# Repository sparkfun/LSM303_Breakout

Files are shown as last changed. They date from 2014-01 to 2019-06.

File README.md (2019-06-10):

**NOTE:** *This product has been retired from our catalog. If you are looking for more up-to-date info, please check out some of these resources to see how other users are still hacking and improving on this product.*
* *[SparkFun Forum](https://forum.sparkfun.com/)*
* *[IRC Channel](https://www.sparkfun.com/news/263)*

LSM303DLMTR Breakout Board
===========================

[LSM303 Breakout
*LSM303DLMTR Breakout Board (SEN-10888)*](https://www.sparkfun.com/products/10888)

The LSM303DLMTR is a triple axis accelerometer and triple axis magnetic sensor, providing 6D of orientation detection.

There is example code available [here](https://github.com/pololu/lsm303-arduino).

Repository Contents
-------------------
* **/Hardware** - All Eagle design files (.brd, .sch)

License Information
-------------------
The hardware is released under [Creative Commons Share-alike 3.0](http://creativecommons.org/licenses/by-sa/3.0/).

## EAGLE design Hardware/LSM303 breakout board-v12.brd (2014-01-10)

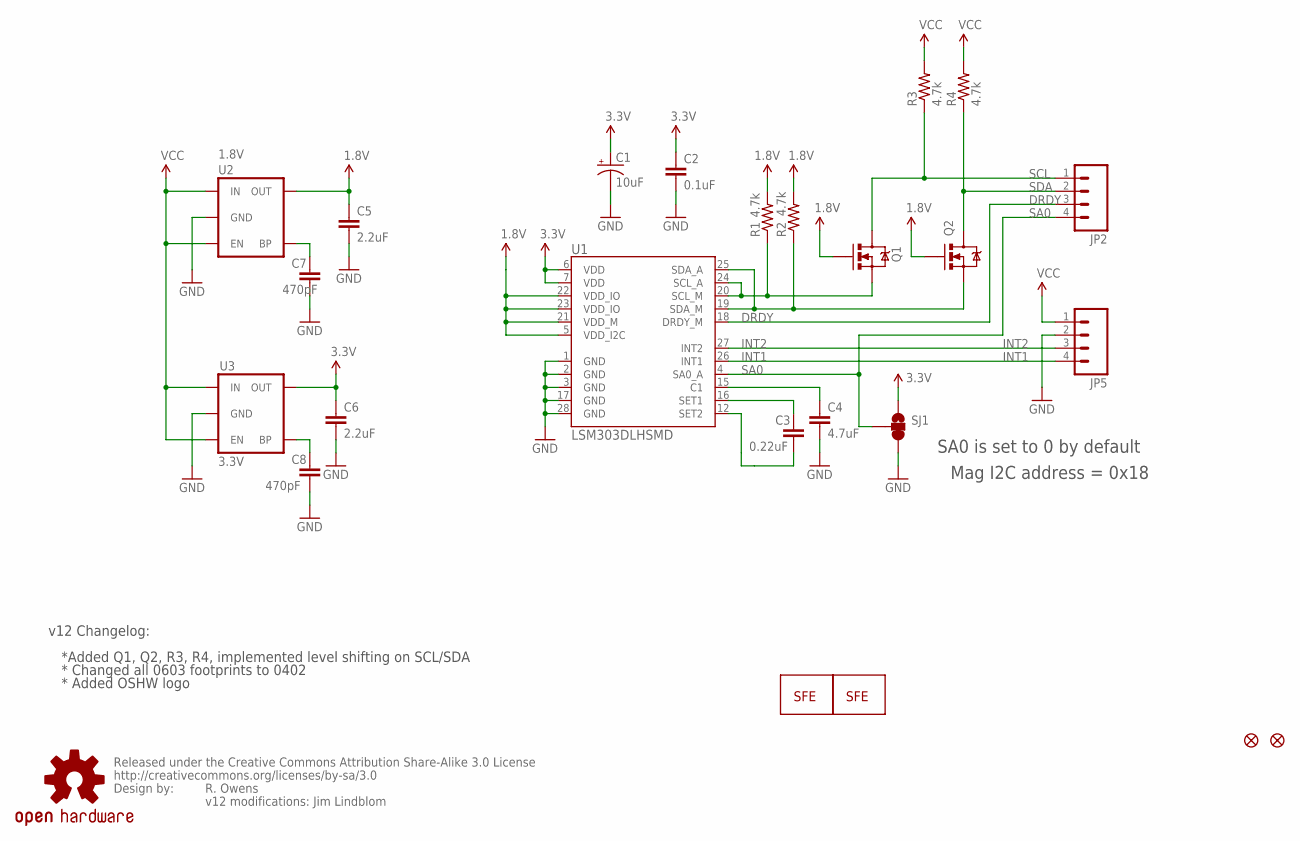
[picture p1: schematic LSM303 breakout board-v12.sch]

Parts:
C1: 10uF; EIA3216
C2: 0.1uF; 0402-CAP
C3: 0.22uF; 0402-CAP
C4: 4.7uF; 0402-CAP
C5, C6: 2.2uF; 0402-CAP
C7, C8: 470pF; 0402-CAP
JP1: LOGO-SFENW2; SFE-NEW-WEB
JP2, JP5: M04PTH; 1X04
JP3, JP4: FIDUCIAL1X2; FIDUCIAL-1X2
JP6: LOGO-SFESK; SFE-LOGO-FLAME
Q1, Q2: MOSFET-N-CH; SOT23-3
R1, R2, R3, R4: 4.7k; 0402-RES
SJ1: SOLDERJUMPER_2WAYPASTE2&3; SJ_3_PASTE2&3
U1: LSM303DLHSMD; LGA28-5X5
U2: 1.8V; SC70
U3: 3.3V; SOT23-5
U$5: CREATIVE_COMMONS
U$8: OSHW-LOGOS; OSHW-LOGO-S

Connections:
1.8V: C5.1, Q1.1 (G), Q2.1 (G), R1.2, R2.2, U1.5 (VDD_I2C), U1.21 (VDD_M), U1.22 (VDD_IO), U1.23 (VDD_IO), U2.5 (OUT)
3.3V: C1.A (+), C2.1, C6.1, SJ1.1, U1.6 (VDD), U1.7 (VDD), U3.5 (OUT)
DRDY: JP2.3, U1.18 (DRDY_M)
GND: C1.C (-), C2.2, C4.2, C5.2, C6.2, C7.2, C8.2, JP5.2, SJ1.3, U1.1 (GND), U1.2 (GND), U1.3 (GND), U1.17 (GND), U1.28 (GND), U2.2 (GND), U3.2 (GND)
INT1: JP5.4, U1.26 (INT1)
INT2: JP5.3, U1.27 (INT2)
unnamed: C7.1, U2.4 (BP)
unnamed: C8.1, U3.4 (BP)
unnamed: C3.1, U1.16 (SET1)
unnamed: C3.2, U1.12 (SET2)
unnamed: C4.1, U1.15 (C1)
SA0: JP2.4, SJ1.2, U1.4 (SA0_A)
SCL: JP2.1, Q1.3 (D), R3.1
SCL_M: Q1.2 (S), R1.1, U1.20 (SCL_M), U1.24 (SCL_A)
SDA: JP2.2, Q2.3 (D), R4.1
SDA_M: Q2.2 (S), R2.1, U1.19 (SDA_M), U1.25 (SDA_A)
VCC: JP5.1, R3.2, R4.2, U2.1 (IN), U2.3 (EN), U3.1 (IN), U3.3 (EN)

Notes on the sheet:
R. Owens
v12 modifications: Jim Lindblom
v12 Changelog:
*Added Q1, Q2, R3, R4, implemented level shifting on SCL/SDA
* Changed all 0603 footprints to 0402
SA0 is set to 0 by default
Mag I2C address = 0x18
* Added OSHW logo

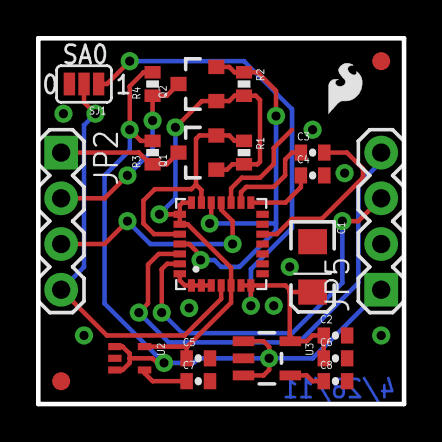
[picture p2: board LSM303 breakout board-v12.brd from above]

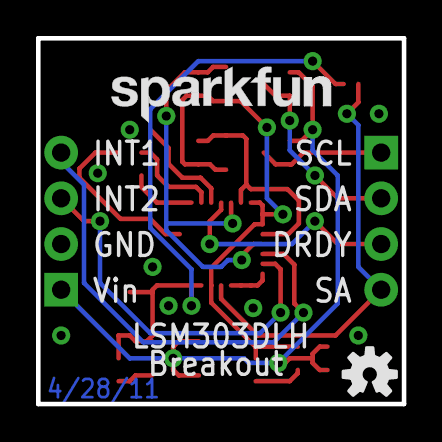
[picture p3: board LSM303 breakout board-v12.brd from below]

Board: 2 copper layers, 20.3 x 20.3 mm, 26 parts (2 on the bottom side), 17 nets.

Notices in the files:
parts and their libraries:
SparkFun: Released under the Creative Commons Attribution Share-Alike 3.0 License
